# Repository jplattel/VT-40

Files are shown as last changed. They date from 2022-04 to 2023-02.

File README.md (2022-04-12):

# My Personal VT-40 (original by [vladantrhlik](https://github.com/vladantrhlik/VT-40/))

40% ortholinear mechanical keyboard, modified to my own taste with a cover for the microcontroller & a custom base-plate.

Personalized VT-40

## Materials

- Raspberry Pi Pico
- Diodes (1N4148)
- PCB (ordered on JLC with `pcb/gerber.zip`)
- Encoders (EC11)
- screws (which type did I use?)
    - m2.5 10mm (2x)    mounting the cover to the Pico
    - m4 15mm (1x)     mounting the cover to the PCB
    - m2 4mm (6x)           bottom plate to PCB 
- Switches (running Kailh Low Profile Choc Red's)
- Keycaps (got a set of [Work Louder Blind](https://worklouder.cc/shop/wrk-blind/))

## Building it

Solder the diodes, put in the headers for the Pico, solder the Pico to the pcb and finally the encoders & switches

I lasered the microcontroller cover out of black HDPE, 3mm thick. Use the file in the `dxf` folder. Carefully mount the cover on the microcontroller. Then use the bigger screw to attach the cover to the PCB. (the screw will self-fasten in the PCB).

Print the two bottom plates, the first one (`bottom-1.stl`) in the color you like, the other one (`bottom-2.stl`) in TPU. Mount `bottom-1` plate to the PCB and attach the `bottom-2` plate with double sided tape.

## Code

See the `src` folder. Updated for the new KMK version which supports the encoders differently. I didn't solder the LEDs, so that's not in there!. Flash KMK to the Pico and copy the `main.py` over when plugging the keyboard in. That's it, ready now!

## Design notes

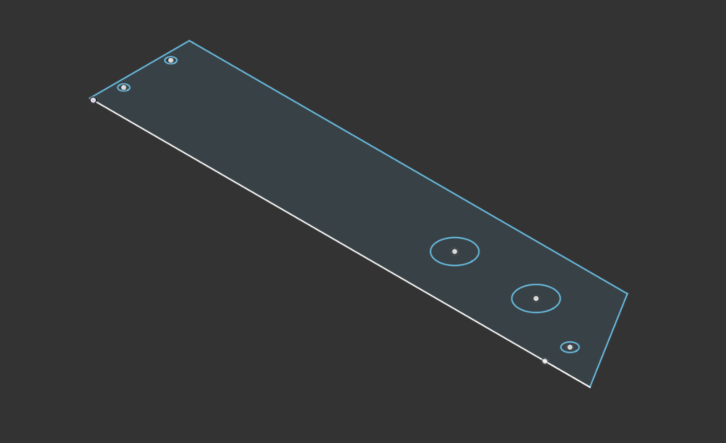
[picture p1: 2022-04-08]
dxf/cover.png

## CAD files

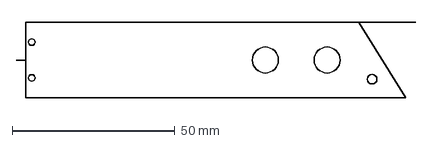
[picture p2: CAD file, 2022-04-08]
dxf/cover.dxf
122.7 x 23.2 mm

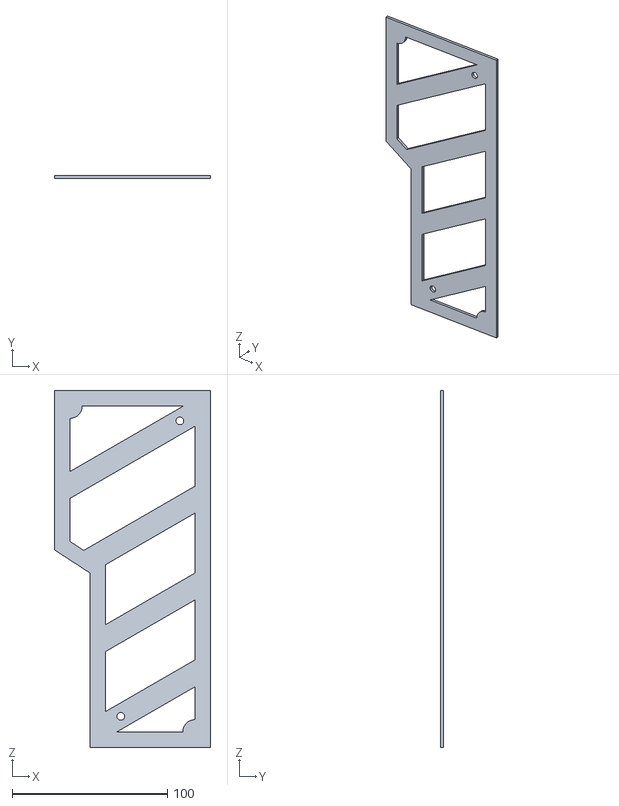
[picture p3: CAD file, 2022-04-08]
stl/bottom-2.stl
100.8 x 2.00 x 230.2

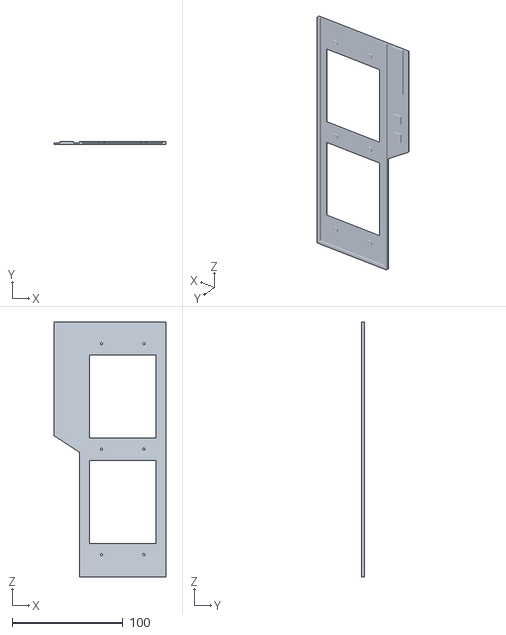
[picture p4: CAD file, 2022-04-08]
stl/bottom-1.stl
100.8 x 2.70 x 230.2

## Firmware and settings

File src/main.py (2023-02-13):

print("Starting VT-40")

import board

from kmk.kmk_keyboard import KMKKeyboard
from kmk.keys import KC
from kmk.modules.encoder import EncoderHandler
from kmk.scanners import DiodeOrientation
from kmk.extensions.media_keys import MediaKeys

keyboard = KMKKeyboard()
keyboard.debug_enabled = True
keyboard.extensions.append(MediaKeys())

keyboard.col_pins = (
    board.GP6,
    board.GP7,
    board.GP8,
    board.GP9,
    board.GP10,
    board.GP11,
    board.GP12,
    board.GP13,
    board.GP21,
    board.GP20,
    board.GP19,
    board.GP18,
)

keyboard.row_pins = (
    board.GP2,
    board.GP3,
    board.GP4,
    board.GP5
)

keyboard.diode_orientation = DiodeOrientation.COLUMNS

encoder_handler = EncoderHandler()
encoder_handler.pins = (
	(board.GP16, board.GP17, None,),
	(board.GP26, board.GP27, None,),
)
encoder_handler.map = [
    (
        (KC.VOLD,KC.VOLU,1),
        (KC.BRID,KC.BRIU,1),
    )
]
keyboard.modules.append(encoder_handler)

keyboard.keymap = [
	[
		KC.ESC,  KC.Q,    KC.W,  	KC.E,   KC.R,   KC.T,   KC.Y,    KC.U,     KC.I,     KC.O,    KC.P,    KC.BKDL, 	
		KC.TAB,  KC.A,    KC.S,  	KC.D,   KC.F,   KC.G,   KC.H,    KC.J,     KC.K,     KC.L,    KC.GRV,  KC.LSFT(KC.BSLS),
		KC.LSFT, KC.Z,    KC.X,  	KC.C,   KC.V,   KC.B,   KC.N,    KC.M,     KC.COMMA, KC.DOT,  KC.UP,   KC.ENT,
		KC.LCTL, KC.LALT, KC.LGUI,	KC.SPC, KC.SPC, KC.SPC, KC.RGUI, KC.RALT,  KC.NO,    KC.LEFT, KC.DOWN, KC.RIGHT,
	],
]

if __name__ == '__main__':
	keyboard.go()

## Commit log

2022-04-08 more docs
    [bottom-1.stl, bottom-2.stl, bottom.stl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]
2023-02-13 fixed encoders
2023-05-16 updated code for the encoders to work
